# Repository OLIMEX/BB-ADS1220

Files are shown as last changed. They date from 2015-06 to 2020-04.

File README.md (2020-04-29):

# BB-ADS1220
OSHW Open Source Hardware breakboard for ADS1220 Low Power Preciese 24-bit ADC from Texas Instruments

## Licensee
* Hardware is released under CERN Open Hardware Licence Version 2 -
Strongly Reciprocal
* Software is released under GPL3 Licensee
* Documentation is released under CC BY-SA 3.0

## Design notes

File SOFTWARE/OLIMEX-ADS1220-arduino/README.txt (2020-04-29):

This archive contains an Arduino IDE example for Olimex BB-ADS1220. A host board is required. Jumper wires to establish proper connection are required. A 0.1" step breadboard would be of great help.

In our setup OLIMEXINO-32U4 was used. We also used Arduino IDE v1.6.2.  

The example prints the voltages that are provided to analog input pin AIN0 over the console terminal of Arduino IDE. The communication protocol between BB-ADS1220 and the host boards is SPI.

Before compiling the project proper hardware connections have to be established. This is really easy if you have a 0.1" step breadboard like BREADBOARD-1.

The hardware connections are quite easy to establish when you are looking at the board's schematic. Make sure to have the schematic in front of you when establishing the hardware connections:

AVSS - GND(-)
AIN0 - analog input pin - provide up to 2.048V (!) voltage source to be measured and displayed
AIN1 - n.c.
AIN2 - n.c.
AIN3 - n.c.
AVDD - +3.3V(+)
REFP - n.c.
REFN - n.c.

VDD	 - +3.3V
DRDY#- to D4 on Olimexino
CS#	 - CS# on UEXT.10
CLK	 - SCK on UEXT.9
DIN  - MOSI on UEXT.8
DOUT - MISO on UEXT.7
GND  - GND(-)
AVSS - GND(-)

Make sure that you have made proper hardware connection between BB-ADS1220 and your main board. Do not provide more than 2.048V to AIN0 - this can damage the board.

To use this example you would need to first close Arduino IDE. Then copy the two folders "libraries" and "examples" to the main installation folder of the Arduino IDE (the folder that contains "arduino.exe"). Select to merge the folders - the folders provided contain only additional files, no changes to your previous libraries or examples would be performed. At this point you can start Arduino IDE and go to File -> Examples -> Olimex ADS1220 -> ads1220_demo. Remember to select the proper board and port in the "Tools". Compile the project and upload to the board. Provide voltage up to 2.048V to AIN0. Open either the Arduino "Serial Monitor" from Tools -> Serial monitor or a favourite terminal program - the voltage that you provided to the board would be measured and printed.

June, 2015

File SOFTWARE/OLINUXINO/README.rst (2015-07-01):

================================
Olimex BB-ADS1220 python example
================================
Description
-----------
BB-ADS1220_ is four channel sigma-delta precise 24-bit adc breakboard.

ADS1220 features two differential or four single-ended inputs through a flexible input multiplexer (MUX), a low-noise,
programmable gain amplifier (PGA), two programmable excitation current sources, a voltage reference, an oscillator, a
low-side switch, and a precision temperature sensor.

FEATURES:

- Fully integrated TI ADS1220
- All IC pins available at the two connector rows
- Each signal is named near the connector
- Breadboard-friendly 0.1" step between pins
- Included plastic headers for easier mounting on a breadboard (not soldered to the board)
- Board dimensions: (750 x 850)mil ~ (19.0 x 21.5)mm

Texas Instruments ADS1220 features:

- Low Current Consumption 120 µA in Duty-Cycle Mode
- Wide Supply Range: 2.3 V to 5.5 V
- Programmable Gain: 1 V/V to 128 V/V
- Programmable Data Rates: Up to 2 kSPS
- Up to 20-Bits Effective Resolution
- Simultaneous 50-Hz and 60-Hz Rejection at 20 SPS with Single-Cycle Settling Digital Filter
- Two Differential or Four Single-Ended Inputs
- Dual Matched Programmable Current Sources: 10 µA to 1.5 mA
- Internal 2.048-V Reference: 5 ppm/°C (typ) Drift
- Internal 2% Accurate Oscillator
- Internal Temperature Sensor: 0.5°C (typ) Accuracy
- SPI-Compatible Interface (Mode 1)

Connection
----------

::

                            ---------------------------------
                            |                               |
                  UEXT(2) - | AVSS                      VDD | - UEXT(1)
                            |                               |
                          - | IN0                     DRDY# | - GPIO3(5)
                            |                               |
                          - | IN1                       CS# | - UEXT(10)
                            |                               |
                          - | IN2                       CLK | - UEXT(9)
                            |                               |
                          - | IN3                       DIN | - UEXT(8)
                            |                               |
                  UEXT(1) - | AVDD                     DOUT | - UEXT(7)
                            |                               |
                          - | REFP                      GND | - UEXT(2)
                            |                               |
                          - | REFN                     AVSS | - UEXT(2)
                            |                               |
                            ---------------------------------

This is minimum required wiring. The signal DRDY# is optional.
Instead of polling it you can just wait some time to be sure that conversation is completed. Also
you can use any available pin. In this example we use GPIO3(5) which is *PH0*.

Running
-------
Download both files (**main.py** and **ADS1220.py**) to some folder, for example ~/ads and run them like this:

::

    cd ~/ads
    python main.py

You should see something like this:

::

    Temperature: 25.53125 C
    AVDD: 3.359197V

*Note*: If you have any issues run these commands:

::

    apt-get update
    apt-get install python-dev python-pip
    pip install --upgrade pyA20

API
----
See *ADS1220* class for detailed information

About
-----

:Author: Stefan Mavrodiev
:Organization: OLIMEX Ltd.
:Contact: support@olimex.com
:Version: 1.0
:Date: 1 JUL 2015

.. _BB-ADS1220: https://www.olimex.com/Products/Breadboarding/BB-ADS1220/open-source-hardware

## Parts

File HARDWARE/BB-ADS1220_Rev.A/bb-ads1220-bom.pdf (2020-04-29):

bb-ads1220

Page 1

Id | Designator | Package | Quantity | Designation
1 | C1,C2,C3 | C_0603 | 3 | 100nF
2 | , | SIP8_Housing | 2 | HN1x8
3 | U1 | TSSOP-16_4.4x5mm_Pitch0.65mm | 1 | ADS1220

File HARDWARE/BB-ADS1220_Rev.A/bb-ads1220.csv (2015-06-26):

Id | Designator | Package | Quantity | Designation | Supplier and ref
1 | C1,C2,C3 | C_0603 | 3 | 104
2 | , | SIP8_Housing | 2 | CONN_01X08
3 | U1 | TSSOP-16_4.4x5mm_Pitch0.65mm | 1 | ADS1220
4 |  | LOGO_OLIMEX_140 | 1
5 |  | LOGO_PBFREE_33 | 1
6 | G*** | LOGO_STATIC_150 | 1 | LOGO

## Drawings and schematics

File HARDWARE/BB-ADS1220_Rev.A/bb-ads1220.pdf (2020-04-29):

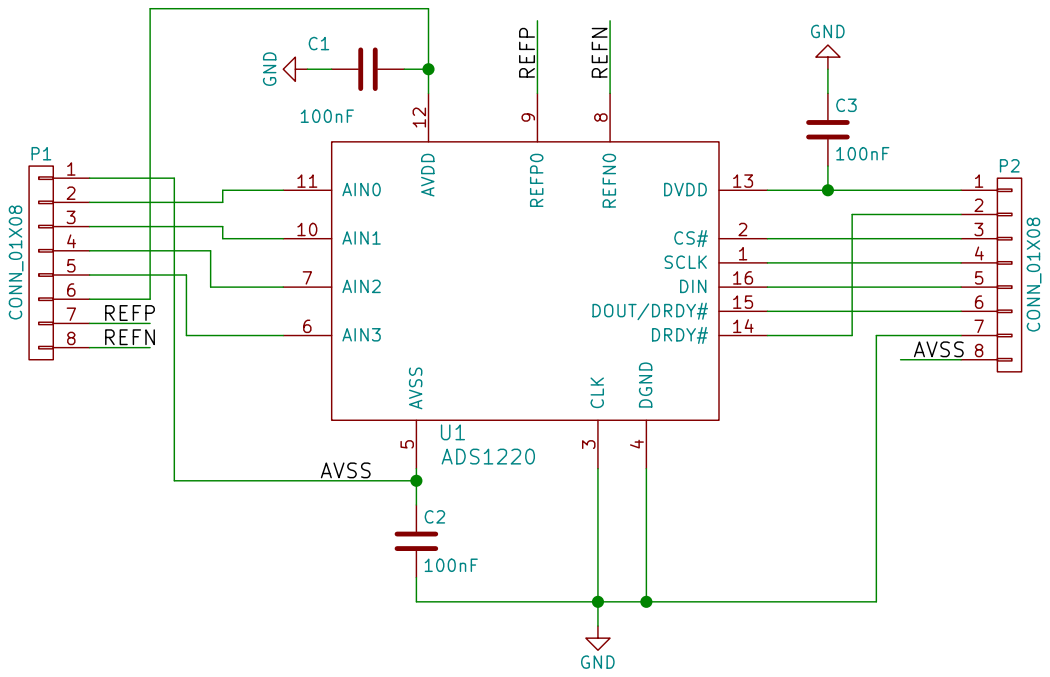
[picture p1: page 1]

9 AIN1 10 AIN0 11 AVDD 12 DVDD 13 DRDY# 14 DOUT/DRDY# 15 DIN 16 U1ADS1220 C3

REFP REFN 7

Id: 1/1 Title: File: bb-ads1220.sch Sheet: / C2

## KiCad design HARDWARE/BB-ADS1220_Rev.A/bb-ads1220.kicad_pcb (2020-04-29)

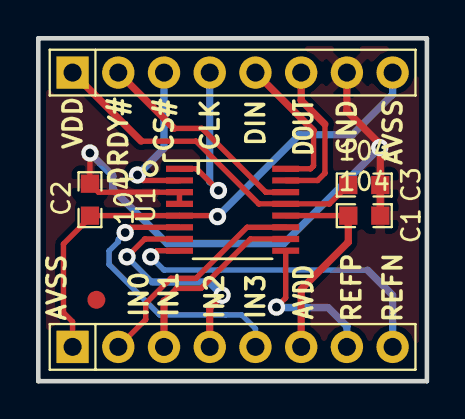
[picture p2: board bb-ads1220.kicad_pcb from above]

Board: 2 copper layers, 21.6 x 19.0 mm, 5 parts (1 on the bottom side), 4 nets.

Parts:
C1, C2, C3: 104; C_0603
OLIMEX_LOGO**: OLIMEX_LOGO_TB
U1: ADS1220; TSSOP-16_4.4x5mm_Pitch0.65mm

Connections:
/AVSS: C2.1, U1.5
GND: C1.1, C2.2, C3.1, U1.3, U1.4
unnamed: C1.2, U1.12
unnamed: C3.2, U1.13

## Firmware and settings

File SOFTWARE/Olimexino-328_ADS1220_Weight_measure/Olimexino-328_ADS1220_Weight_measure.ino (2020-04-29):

/*********************************************************************************************************
 Sample demo software for Olimexino-328 rev.C with weight sensor (SNS-WS50KG)
 and BB-ADS1220 module connected to the SPI pins of the UEXT.
 In order to work properly the pins must be connected as shown below.
 The project is tested with Arduino IDE 1.6.5.

 Note: On this illustration:
 - the asterisk sign (*) means there is a junction between the crossed lines.
 - the plus sign (+) means the crossed lines ARE NOT CONNECTED!


Weight sensor               BB-ADS1220                          Olimexino-328     
SNS-WS50KG                                                         (UEXT)         
                                                              pin   UEXT   arduino
                                                              fun    pin     pin  
white ----*---------*----------------------------------|                          
          |         |                                  |                          
          |         |  |------------------|            |                          
          |     |---+--|AVSS           VDD|------------*----  3.3V    1           
        1Kohm   |   |  |                  |                                       
          |     |   *--|IN0          ~DRDY|                                       
          |     |   |  |                  |                                       
          *-----+---+--|IN 1           ~CS|-----------------  ~CS    10     (D7)  
          |     |   |  |                  |                                       
red   ----+-----+---+--|IN 2           CLK|-----------------  SCK     9     (D13) 
          |     |   |  |                  |                                       
        1Kohm   *---+--|IN 3           DIN|-----------------  MOSI    8     (D11) 
          |     |   |  |                  |                                       
black ----*-----|   |--|AVDD          DOUT|-----------------  MISO    7     (D12) 
          |            |                  |                                       
          |            |REFP0          GND|-----------------  GND     2           
         GND           |                  |                                       
                       |REFN0         AVSS|                                       
                       |------------------|                                        


If connected properly when you program the Olimexino board with this software,
on the Serial monitor you will see received data from the ADS1220 with interval
determined by the macro INTERVAL (in milliseconds).
The three bytes of data will be shown on different lines.

You can find detailed information about the ADS1220 module on the datasheet provided on our website:
https://www.olimex.com/Products/Breadboarding/BB-ADS1220/resources/ads1220.pdf

Date:  2015/12/10
*********************************************************************************************************/

#include <SPI.h>
#include <String.h>

const int chipSelectPin = 7;

#define CS_OUT()  pinMode(chipSelectPin, OUTPUT)
#define CS(Val)   digitalWrite (chipSelectPin, Val)

#define INTERVAL  1000  // ms
#define RECEIVED_BYTES  3
unsigned char Data[RECEIVED_BYTES], i;
char Buff[20];

void setup()
{
  Serial.begin(9600);

  // start the SPI library:
  SPI.begin();
  // configure the SPI - ADS1220 module works ONLY in SPI_MODE1! (datasheet page 33)
  SPI.beginTransaction(SPISettings(4000000, MSBFIRST, SPI_MODE1));

  // initalize the chip select pins:
  CS_OUT();
  CS(HIGH);

  // initialize the module in resistive bridge management mode
  CS(LOW);
  SPI.transfer(0x43); // trigger write to registers command, from address 0, 4 (3+1) bytes - datasheet page 35, table 14
  // Resistive bridge management mode - datasheet page 57, table 26 (values and description of the values)
  // set the four registers (pages 38-42)
  SPI.transfer(0x3E); // register 0x00
  SPI.transfer(0x04); // register 0x01
  SPI.transfer(0x98); // register 0x02
  SPI.transfer(0x00); // register 0x03
  CS(HIGH);
}

void loop()
{
  // start conversion
  CS(LOW);
  SPI.transfer(0x08); // trigger start conversion, datasheet page 35
  CS(HIGH);

  // read data
  CS(LOW);
  SPI.transfer(0x10); // trigger read data command, datasheet page 35
  for (i=0; i<RECEIVED_BYTES; i++)
    Data[i] = SPI.transfer(0);
  CS(HIGH);

  // print data
  for (i=0; i<RECEIVED_BYTES; i++)
  {
    sprintf (Buff, "Byte[%d] = %d\n", i, Data[i]);
    Serial.print (Buff);
  }
  Serial.println ();

  // few milliseconds delay before next reading
  delay (INTERVAL);
}

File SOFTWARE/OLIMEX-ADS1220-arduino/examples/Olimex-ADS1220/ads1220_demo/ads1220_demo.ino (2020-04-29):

#include <Protocentral_ADS1220.h>
#include <SPI.h>
#include <Wire.h>
#define OLIMEXINO_32U4


#define PGA 1
#define VREF 2.048
#define VFSR VREF/PGA
#define FSR (((long int)1<<23)-1)

volatile byte MSB;
volatile byte data;
volatile byte LSB;
volatile byte *SPI_RX_Buff_Ptr;


Protocentral_ADS1220 ADS1220;

void setup()   {

 #ifdef OLIMEXINO_32U4
    // Power Up UEXT
   pinMode(8, OUTPUT);
   digitalWrite(8, HIGH);
   delay(1000);
   digitalWrite(8, LOW);
   delay(500);
  pinMode(ADS1220_CS_PIN, OUTPUT);
  pinMode(ADS1220_DRDY_PIN, INPUT);
  
  ADS1220.begin();
 #endif   
  
  
 Serial.begin(9600);
 Serial.println("BBS-ADS1220 Demo aplication");

 }


void loop() {
    long int bit32;
  long int bit24;
  byte *config_reg;
  float Vout;
  
   SPI_RX_Buff_Ptr = ADS1220.Read_Data();
   
    if(ADS1220.NewDataAvailable = true)
  {
  ADS1220.NewDataAvailable = false;

  MSB = SPI_RX_Buff_Ptr[0];    
  data = SPI_RX_Buff_Ptr[1];
  LSB = SPI_RX_Buff_Ptr[2];

  bit24 = MSB;
  bit24 = (bit24 << 8) | data;
  bit24 = (bit24 << 8) | LSB;                                 // Converting 3 bytes to a 24 bit int
    
  /*if (MSB & 0x80)
    bit32 = (bit24 | 0xFF000000);             // Converting 24 bit two's complement to 32 bit two's complement
  else    
    bit32 = bit24;
  */
  
  bit24= ( bit24 << 8 );
  bit32 = ( bit24 >> 8 );                      // Converting 24 bit two's complement to 32 bit two's complement
  
  Vout = (float)((bit32*VFSR*1000)/FSR);     //In  mV
  }
   
Serial.print(Vout);Serial.println("mV");

  delay(500);

}

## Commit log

2015-06-26 initial release KiCAD files
    [bb-ads1220.csv, bb-ads1220.kicad_pcb, bb-ads1220.sch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]
2015-06-29 schematic update
2015-07-01 Added OLinuXino python example
    [bb-ads1220.csv, bb-ads1220.kicad_pcb, bb-ads1220.sch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]
2015-07-01 Deleted duplicated files
    [bb-ads1220.csv, bb-ads1220.kicad_pcb, bb-ads1220.sch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]
2020-04-29 update docs, software
    [bb-ads1220-bom.odf.ods, bb-ads1220.csv, bb-ads1220.kicad_pcb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]

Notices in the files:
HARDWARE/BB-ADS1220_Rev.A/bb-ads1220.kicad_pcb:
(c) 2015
